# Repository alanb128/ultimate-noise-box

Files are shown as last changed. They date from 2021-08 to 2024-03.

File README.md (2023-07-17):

# ultimate-noise-box
Turn a Raspberry Pi into the ultimate relaxation machine that plays soothing wav files.

## Overview
Here are the features of the Ultimate Noise Machine:
- Produces CD-quality stereophonic audio.
- Uses real audio samples with gapless undetectable looping
- Line level audio output jack to use with high quality powered speakers
- Intuitive control panel with rotary wheel and LCD screen
- Web-based control too with a responsive UI

This is the full-size unit based on a Raspberry Pi 3 with custom 3D-printed faceplate:

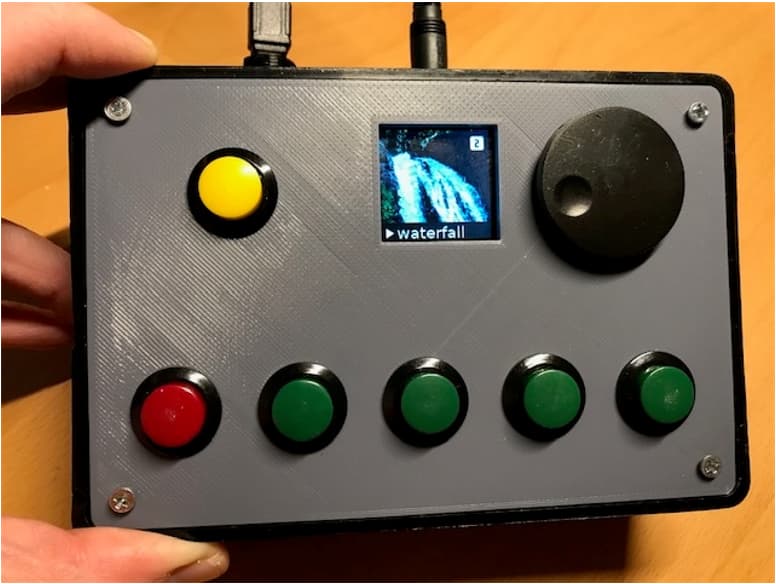
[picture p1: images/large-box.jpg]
Large version


The smaller version uses smaller buttons and a Raspberry Pi Zero 2W:

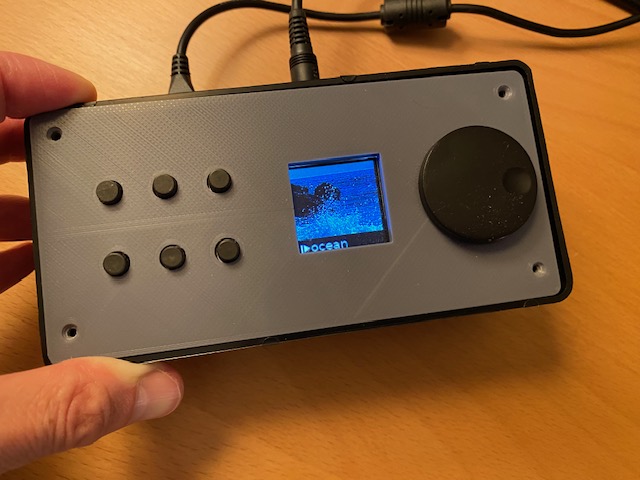
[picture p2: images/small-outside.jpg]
Small version


## Building it

### Parts list

At a minimum, you need a Pi and the audio bonnet specified below. If you don't use the buttons, rotary encoder, or display, you can control the Noise Box from its built-in web page by browsing to the device's IP address or enabling the Public URL feature.

- Raspberry Pi 3, 4, or Zero 2W
- [Adafruit I2S Audio Bonnet](https://www.adafruit.com/product/4037)
- Momentary SPST pushbutton such as [this one](https://www.adafruit.com/product/1504)
- 1.44 inch TFT [LCD screen](https://www.adafruit.com/product/2088)
- [Rotary encoder](https://www.adafruit.com/product/377) (why not get a nice [knob](https://www.adafruit.com/product/2055) too?)
- [I2C Rotary Encoder Breakout](https://www.adafruit.com/product/4991)

### Assembly

Wire the switches into the audio bonnet following the schematic below. You can solder directly into the pads on the bonnet, which show the GPIO number.

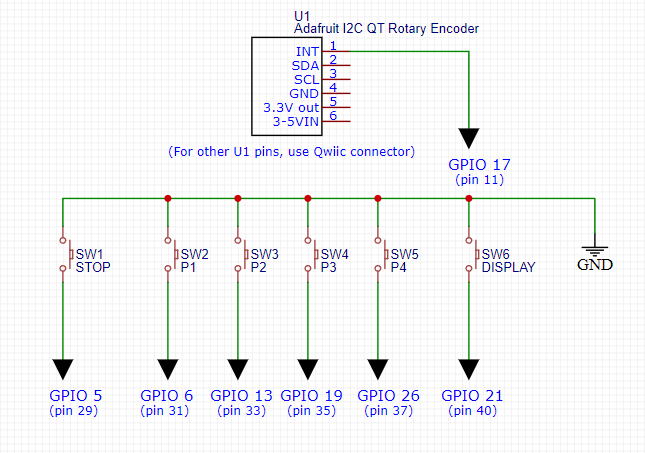
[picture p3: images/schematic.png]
Schematic


Wire the LCD into the bonnet using the diagram for the 1.44" display found [here](https://learn.adafruit.com/adafruit-1-44-color-tft-with-micro-sd-socket/python-wiring-and-setup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).

Solder the rotary encoder to the encoder board as detailed [here](https://learn.adafruit.com/adafruit-i2c-qt-rotary-encoder/overview). Finally, wire the rotary encoder board into the bonnet. You could use the Qwiic connector on one end, but either way the INT terminal on the rotary board will need to be wired in to GPIO 17.

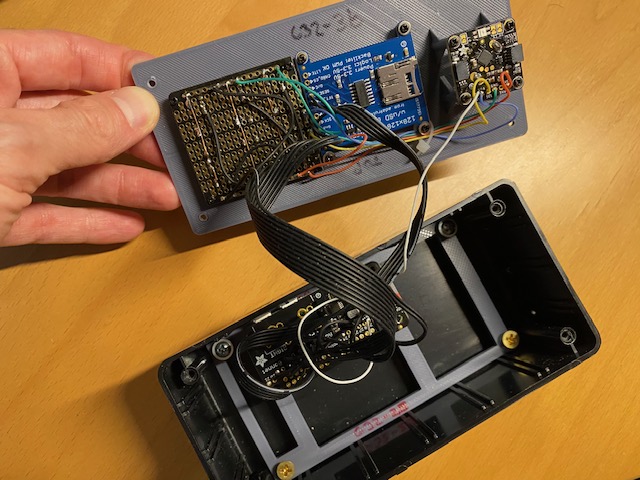
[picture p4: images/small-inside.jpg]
Inside wiring


Attach the audio bonnet to the Pi.

### Case

Use your favorite project case, and to enhance the project, print your own faceplate to mount the controls. You can find STL files in this repo for the 3D faceplates used in the pictures above. Unfortunately [the cases](https://www.radioshack.com/products/radioshack-project-enclosure-6x4x2) used for them no longer appear available from Radio Shack online.

## Software

This project uses the [balena platform](https://www.balena.io/) for ease of deployment, device management and as the best way to run containers on the Pi. Sign up for a free account - the first 10 devices are free and fully featured. After assembling your hardware and creating a balena account, simply click the button below to generate a microSD card image to burn and insert in your Pi:

balena deploy button (https://dashboard.balena-cloud.com/deploy?repoUrl=https://github.com/alanb128/ultimate-noise-box)

After you create a fleet, add a new device. Choose the type of Pi you'll be using and you can also add your WiFi credentials at this point. You'll be able to download the SD card image after you add the device. You can use [balenaEtcher](https://etcher.balena.io/) to burn your SD card image. After powering on your Pi, it should start downloading the software.

After the software has downloaded, you'll need to go into the device configuration in balenaCloud and add the following configuration variable:

`BALENA_HOST_CONFIG_dtoverlay`

With the value:

`"hifiberry-dac","i2s-mmap"`

If you want to make your own changes to the software, clone this repo and use the [balena CLI](https://github.com/balena-io/balena-cli) to push the modified code to your device.

## Setup and use

The unit comes with nine pre-recorded relaxation sounds. To add more sounds, browse to the device's IP address (you can find it on the dashboard) on port 9000. (i.e. 192.168.1.100:9000 - but use your IP) The initial login for the Minio browser is `myminio`/`myminio123` here you can drag and drop additional sound files. They must be of the following type: uncompressed PCM format wav files. The sound file should be optimized for looping playback. If you would like an accompanying image for each sound file, give it the same name but with a .jpg file extension. Images should be 128x128 pixels. After uploading additional files, you should reboot the device from the balenaCloud dashboard.

You can scroll through the available sounds by rotating the wheel. Push the wheel to play the selected sound. The stop button stops playback of the current sound.

The display button cycles through the volume display and the device info display. You can adjust the volume level with the wheel when the volume bar is displayed, however controlling the actual volume is currently not implemented.

The four preset buttons instantly start playing the preset sound. To store a preset, open the web interface to the device by browsing its IP address (port 80).

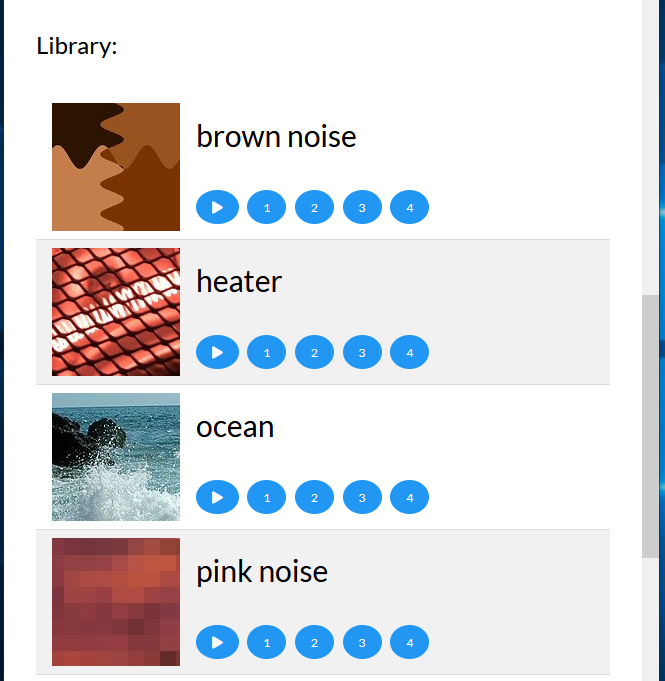
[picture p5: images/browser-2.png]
Web page


Next to each sound you'll see buttons labeled 1 - 4. Click the button number next to a sound to assign it to that preset number.

## How it works

The application is made up of multiple [containers](https://docs.docker.com/get-started/what-is-a-container/) that communicate with each other through APIs and also share a storage volume. This project is a great example of how containers can work together and cleanly separate functionality. Also note how we add entire functionality by pulling images made by the various software authors. 

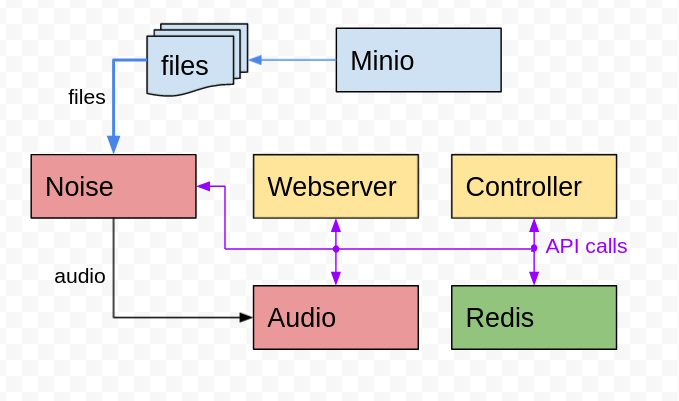
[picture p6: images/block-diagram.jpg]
Block diagram


Here is a summary of the function of each container:

### Noise
This is the Python program that plays back the audio files through the audio block. It uses Pygame to achieve gapless looping playback. The audio files must be in uncompressed PCM wav file format. It exposes an API (using FlaskAPI) 
- `GET /` returns the current status (`status`) and currently playing file (`file`) and a list of valid API calls.
- `POST /play/<noisename>/` immediately starts looping playback of specified noise, and returns the current status (`status`) and currently playing file (`file`)
- `POST /stop/` immediately stops any file playback, and returns the current status (`status`)

Note `<noisename>` and returned file are the name of the noise, with no path or extension, and underscore (_) instead of spaces.

### Webserver
This is a Node/Express webserver that generates a single page for stopping or starting a noise from the library or presets. It is also currently the only place you can assign presets to noises. The four presets mirror the four physical buttons on the hardware control panel. This application uses XMLHttpRequest to communicate with the backend for stopping, starting and assigning presets. It is set to run on port 80 by default and can be made available outside your network if you enable the device's [public URL](https://www.balena.io/docs/learn/develop/runtime/#public-device-urls).

### [Redis](https://redis.io/)
An in-memory data structure store. It can periodically write to the local storage as well. This is used to store and retreive the values of the preset buttons, last volume level and most recently played file.

### [Minio](https://min.io/)
S3 compatible object storage. This provides a web interface for uploading new audio files and their associated jpegs to the device. To access the interface, browse to the local URL using port 9000. To change the username and password, set new values in the `docker-compose.yml` file before first use! (You'll need to clone this repo and push using the CLI in order to do this.)

### Audio
This is the versatile balena [audio block](https://github.com/balenablocks/audio) that runs a PulseAudio server optimized for balenaOS and is the core of [balenaSound](https://sound.balenalabs.io/). We use it here to take care of setting up and routing all audio needs on the Pi hardware, so the noise container just sends its audio here.

### Controller
A custom Python program that responds to button presses on the control panel, reads the rotary dial position and drives the LCD display.

## Credits

Some of the included sounds and their accompanying images were derived from the following royalty-free image and sound libraries:

Waterfall sound by <a href="https://pixabay.com/users/nickype-10327513/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">NickyPe</a> from <a href="https://pixabay.com//?utm_source=link-attribution&utm_medium=referral&utm_campaign=music&utm_content=121190">Pixabay</a>

Splash sound by <a href="https://pixabay.com/users/juliush-3921568/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">JuliusH</a> from <a href="https://pixabay.com/sound-effects//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">Pixabay</a>

Rain sound by <a href="https://pixabay.com/users/sergei_spas-9611130/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">sergei_spas</a> from <a href="https://pixabay.com/sound-effects//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">Pixabay</a>

Brown image extracted from photo by <a href="https://unsplash.com/@pawel_czerwinski?utm_source=unsplash&utm_medium=referral&utm_content=creditCopyText">Pawel Czerwinski</a> on <a href="https://unsplash.com/backgrounds/colors/brown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">Unsplash</a>

Pink noise image extracted from photo by <a href="https://unsplash.com/@joelfilip?utm_source=unsplash&utm_medium=referral&utm_content=creditCopyText">Joel Filipe</a> on <a href="https://unsplash.com/photos/Mbf3xFiC1Zo?utm_source=unsplash&utm_medium=referral&utm_content=creditCopyText">Unsplash</a>

Underwater image extracted from photo by <a href="https://unsplash.com/@hisarahlee?utm_source=unsplash&utm_medium=referral&utm_content=creditCopyText">Sarah Lee</a> on <a href="https://unsplash.com/photos/QURU8IY-RaI?utm_source=unsplash&utm_medium=referral&utm_content=creditCopyText">Unsplash</a>

Rain image extracted from photo by <a href="https://unsplash.com/@janfillem?utm_source=unsplash&utm_medium=referral&utm_content=creditCopyText">Jan-Willem</a> on <a href="https://unsplash.com/photos/FobwhDUgdrk?utm_source=unsplash&utm_medium=referral&utm_content=creditCopyText">Unsplash</a>
  
Splash image extracted from photo by <a href="https://unsplash.com/@amadejtauses?utm_source=unsplash&utm_medium=referral&utm_content=creditCopyText">Amadej Tauses</a> on <a href="https://unsplash.com/photos/xWOTojs1eg4?utm_source=unsplash&utm_medium=referral&utm_content=creditCopyText">Unsplash</a>

Waterfall photo by <a href="https://unsplash.com/@nathananderson?utm_source=unsplash&utm_medium=referral&utm_content=creditCopyText">Nathan Anderson</a> on <a href="https://unsplash.com/wallpapers/nature/waterfall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">Unsplash</a>

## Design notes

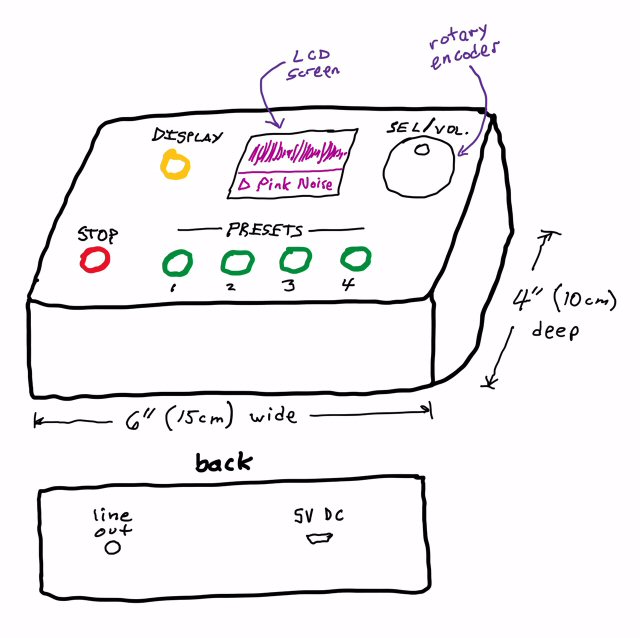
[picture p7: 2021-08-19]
initial_plan-50.jpeg

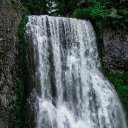
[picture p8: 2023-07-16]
noise/assets/waterfall.jpg

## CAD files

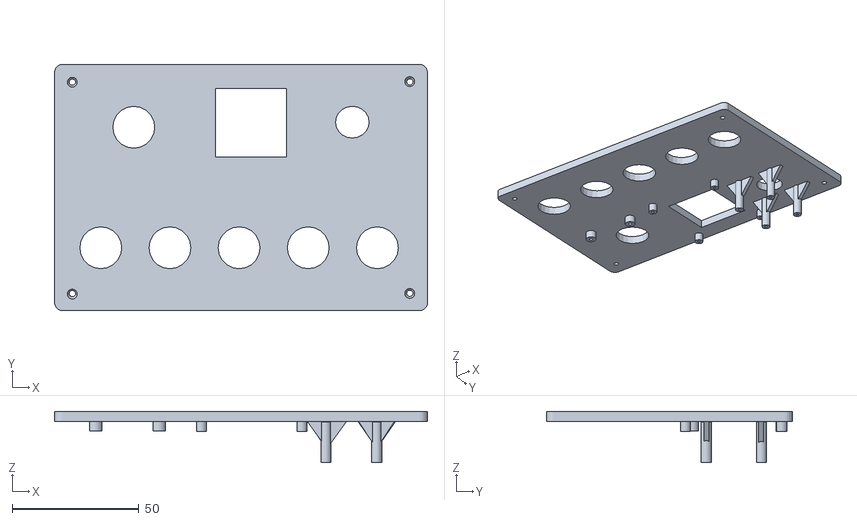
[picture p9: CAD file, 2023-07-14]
stl/large-faceplate.stl
147.0 x 97.0 x 20.2

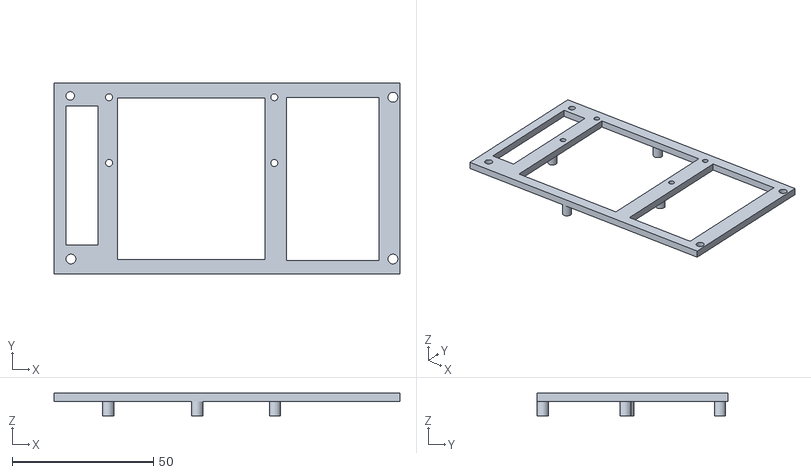
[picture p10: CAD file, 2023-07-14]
stl/small-case-bracket.stl
122.5 x 67.5 x 8.00

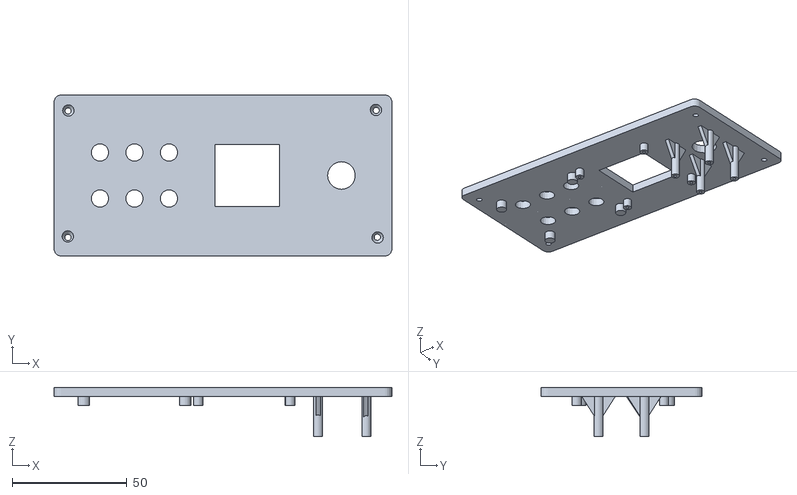
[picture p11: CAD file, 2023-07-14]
stl/small-faceplate.stl
147.0 x 70.0 x 21.5

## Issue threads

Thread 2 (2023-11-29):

Error trying to deploy release at the minio phase

matrix9777, 2023-11-29:
Would you have a solution to this error?

[Error]       Some services failed to build:
[Error]         Service: minio
[Error]           Error: no matching manifest for linux/arm/v6 in the manifest list entries
[Info]        Built on 3c65b7a
[Error]       Not deploying release.

alanb128, 2023-11-29:
I don't think Minio has a version for the armV6 architecture. Are you using a Pi Zero? Upgrading to an armV7 or higher device like the Pi 3, 4 or Zero 2 would probably fix it. To make it work on your current device, you could delete the Minio section of the docker-compose but you would need to use another method to upload the audio/image files to your device.

matrix9777, 2023-11-29:
Thank you for the fast response. Do you have a suggestion on the best way to modify the code that it's trying to push to Balena? It doesn't give me an edit option on the Balena site, it just tries to deploy, then errors out when it can't complete the operation without an option to edit what it's trying to compile.
Thanks in advance.

alanb128, 2023-11-30:
You can clone this repo to your local machine, make the modifications, then push the changed code as a release to your fleet (of one device) using the balena CLI. (It may sound like a lot of steps, but it's actually pretty quick.) You can see the step-by-step instructions here: https://docs.balena.io/learn/getting-started/raspberrypi3/python/ - you've already completed some of the steps, so note the section about using the CLI.

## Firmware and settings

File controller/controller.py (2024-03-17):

import digitalio 
import board 
from PIL import Image, ImageDraw, ImageFont 
try:
    import adafruit_rgb_display.ili9341 as ili9341 
    import adafruit_rgb_display.st7789 as st7789 # pylint: disable=unused-import 
    import adafruit_rgb_display.hx8357 as hx8357 # pylint: disable=unused-import 
    import adafruit_rgb_display.st7735 as st7735 # pylint: disable=unused-import 
    import adafruit_rgb_display.ssd1351 as ssd1351 # pylint: disable=unused-import 
    import adafruit_rgb_display.ssd1331 as ssd1331 # pylint: disable=unused-import
except:
    print("No display found, going headless!")
    USE_DISPLAY = False
else:
    USE_DISPLAY = True

import time 
import subprocess 
import datetime 
import RPi.GPIO as GPIO 
import requests
import redis 
import os
try:
    from adafruit_seesaw import seesaw, rotaryio
except:
    print("No rotary encoder found, disabling rotary control!")
    USE_ROTARY = False
else:
    USE_ROTARY = True

# Adafruit I2C QT Rotary Encoder
# Using the INT output on Pi GPIO 17
try:
    seesaw = seesaw.Seesaw(board.I2C(), addr=0x36)
except:
    print("Error initializing the rotary encoder board.")
    USE_ROTARY = False
else:
    seesaw_product = (seesaw.get_version() >> 16) & 0xFFFF
    print("Found seesaw supported product {}".format(seesaw_product))
    if seesaw_product != 4991:
        print("Wrong firmware loaded for QT encoder?  Expected 4991")
    # Set up the rotary click button, and add to interrupt
    seesaw.pin_mode(24, seesaw.INPUT_PULLUP)  # Pin on the QT
    seesaw.set_GPIO_interrupts(1 << 24, True)
    seesaw.enable_encoder_interrupt()

# TFT configuration for CS and DC pins:
cs_pin = digitalio.DigitalInOut(board.CE0) #pin24
dc_pin = digitalio.DigitalInOut(board.D25) #pin22
reset_pin = digitalio.DigitalInOut(board.D24) #pin18

# Config for display baudrate (default max is 24mhz):
BAUDRATE = 24000000

# Setup SPI bus using hardware SPI:
spi = board.SPI()

try:
    # pylint: disable=line-too-long
    # Create the display:
    # disp = st7789.ST7789(spi, rotation=90,                            # 2.0" ST7789
    # disp = st7789.ST7789(spi, height=240, y_offset=80, rotation=180,  # 1.3", 1.54" ST7789
    # disp = st7789.ST7789(spi, rotation=90, width=135, height=240, x_offset=53, y_offset=40, # 1.14" ST7789
    # disp = hx8357.HX8357(spi, rotation=180,                           # 3.5" HX8357
    disp = st7735.ST7735R(spi, rotation=90,                           # 1.8" ST7735R
    #disp = st7735.ST7735R(spi, rotation=270, height=128, x_offset=2, y_offset=3,   # 1.44" ST7735R
    # disp = st7735.ST7735R(spi, rotation=90, bgr=True,                 # 0.96" MiniTFT ST7735R
    # disp = ssd1351.SSD1351(spi, rotation=180,                         # 1.5" SSD1351
    # disp = ssd1351.SSD1351(spi, height=96, y_offset=32, rotation=180, # 1.27" SSD1351
    # disp = ssd1331.SSD1331(spi, rotation=180,                         # 0.96" SSD1331
        cs=cs_pin,
        dc=dc_pin,
        rst=reset_pin,
        baudrate=BAUDRATE,
    )
except:
    print("No display or error setting up display.")
    disp = False
    USE_DISPLAY = False

if USE_DISPLAY:
    # Create blank image for drawing.
    # Make sure to create image with mode 'RGB' for full color.
    if disp.rotation % 180 == 90:
        height = disp.width  # we swap height/width to rotate it to landscape!
        width = disp.height
    else:
        width = disp.width  # we swap height/width to rotate it to landscape!
        height = disp.height
else:
    # set a default h, w even if no display so image routines don't error out
    width = 128
    height = 128

# Main RGB image
image = Image.new("RGB", (width, height))

# image for info area
img_info = Image.new("RGB", (128, 20), (0, 0, 0))

# create idle image
idle_image = Image.new("RGB", (width, height))

# image for about screen
img_about = Image.new("RGB", (width, height))

# tiny images for fwd/rev wheel icon
img_right = Image.new('RGB', (20, 20), (0, 0, 0))
img_left = Image.new('RGB', (20, 20), (0, 0, 0))

# Drawing object for main display image
draw = ImageDraw.Draw(image)

wav_list = []  # list of available wav files to play (strings)
img_list = []  # list of images to display for each wav file (images)
vol_list = []  # list of volume bars representing volumes (images)
noise_pointer = 0  # index of currently displayed noise image when rotating wheel (int)
rotary_pos = 0  # keeps track of wheel position
now_playing = ""  # name of currently playing file or emply string
display_mode = 0  # int display mode (0-2)
current_volume = 10  # default current volume if none saved (0-20)
new_volume = 10 # variable to see if volume has changed
loop_count = 0  # loop counter for checking the current sound status
IMAGE_PATH = os.getenv('MEDIA_PATH', "/data/my_data/noise/")  # string path to noise and images
ASSET_PATH = os.getenv('ASSET_PATH', "/data/my_data/assets/") # string path to non-noise assets
TEXT_FONT = ImageFont.truetype("/usr/share/fonts/truetype/dejavu/DejaVuSans.ttf", 18)
ICON_FONT = ImageFont.truetype("/usr/src/app/materialdesignicons-webfont.ttf", 20)
DEBOUNCE = 600  # switch debounce time in ms
rot_first = datetime.datetime.now()
rot_last = datetime.datetime.now()

P1_GPIO = 6
P2_GPIO = 13
P3_GPIO = 12 # was 19
P4_GPIO = 20
DISP_GPIO = 22 # was 21
STOP_GPIO = 5

def lib_setup():
    #
    # Generate list of all sound files available,
    # create list of all images with titles burned in,
    # create volume image list
    # create wheel icon images
    #
    global wav_list, img_list, img_info, img_left, img_right
    # Get all sound files in folder
    dir_list = os.listdir(IMAGE_PATH)
    font = ImageFont.truetype("/usr/share/fonts/truetype/dejavu/DejaVuSans.ttf", 18)
    # for each file:
    for d in dir_list:
        if d[-4:] == ".wav":
            save_image = Image.new("RGB", (width, height))
            save_draw = ImageDraw.Draw(save_image)
            save_draw.rectangle((0, 0, width, height), fill=(0, 0, 0)) # draw black box
            noise_name = d[:len(d) - 4]
            wav_list.append(noise_name)
            try:
                i = Image.open(IMAGE_PATH + noise_name + ".jpg")
            except:
                i = Image.open(ASSET_PATH + "default.jpg")
            if width > 128:
                i = i.resize((width, 128))
            save_image.paste(i, (0,0))
            save_image.paste(img_info, (0, 108))
            text = noise_name.replace("_", " ")
            save_draw.text((20, 110), text, font=font, fill=(255, 255, 255),)
            img_list.append(save_image)
    # generate a list of 20 vol images:
    for v in range(0, 21):
        save_image = Image.new("RGB", (width, height))
        save_draw = ImageDraw.Draw(save_image)
        save_draw.rectangle((0, 0, width, height), fill=(0, 0, 0))  # draw black box
        i = Image.open(ASSET_PATH + "vol_" + "{:0>3}".format(v * 5) + ".jpg")
        save_image.paste(i, (0,50))
        text = "volume: " + str(v * 5) + " %"
        save_draw.text((20, 110), text, font=font, fill=(255, 255, 255),)
        save_draw.text((1, 110), "\U000F057F", font=ICON_FONT, fill=(255, 255, 255),)
        vol_list.append(save_image)

    # wheel icon images
    wheel_draw = ImageDraw.Draw(img_left)
    wheel_draw.text((1, 1), "\U000F04D5", font=ICON_FONT, fill=(255, 255, 255),)  # draw the left sel icon
    wheel_draw = ImageDraw.Draw(img_right)
    wheel_draw.text((1, 1), "\U000F04D7", font=ICON_FONT, fill=(255, 255, 255),)  # draw the right sel icon

def create_idle_image():
    #
    # Create the idle image!
    #
    global idle_image
    idle_image_raw = Image.new("RGB", (width, height))
    try:
        idle_image_raw = Image.open(ASSET_PATH + "idle.jpg")
    except:
        # if no idle image found, draw a rectangle instead
        idle_image_draw = ImageDraw.Draw(idle_image_raw)
        idle_image_draw.rectangle((0, 0, width, height), fill=(0, 100, 200))
    if width > 128:
        idle_image_raw = idle_image_raw.resize((width, 128))
    idle_image.paste(idle_image_raw, (0,0))  # use idle image
    idle_draw = ImageDraw.Draw(idle_image)
    idle_image.paste(img_info, (0, 108))
    idle_draw.text((1, 110), "\U000F04DB", font=ICON_FONT, fill=(255, 255, 255),)  # draw the stop icon
    #font = ImageFont.truetype("/usr/share/fonts/truetype/dejavu/DejaVuSans.ttf", 18)
    idle_draw.text((20, 110), "(idle)", font=TEXT_FONT, fill=(255, 255, 255),)

# Setup initial state
def init_controller():
    print("init display")
    global disp, image, draw, now_playing, idle_image

    try:
        image = Image.open(ASSET_PATH + "splash.jpg")
    except:
        print("Error accessing splash.jpg - using default splash screen instead.")
        # Draw a blue box for init display
        draw.rectangle((0, 0, width, height), fill=(0, 0, 72))

        # Load a TTF Font
        font = ImageFont.truetype("/usr/share/fonts/truetype/dejavu/DejaVuSans.ttf", 24)

        # Draw splash screen
        text = "Welcome!"
        draw.text((3, 10), text, font=font, fill=(255, 255, 0),)
    else:
        if USE_DISPLAY:
            if width > 128:
                image = image.resize((width, 128))
            disp.image(image)
    time.sleep(1)
    lib_setup()
    time.sleep(1)
    create_idle_image()
    time.sleep(1)
    display_info()

    # get current status
    r = requests.get('http://noise:5000/')
    j = r.json()

    print(j)
    if j["status"] == "stop":
        now_playing = ""
        display_now(idle_image)
    else:
        now_playing = j["file"]
        print("now playing: ", now_playing)
        display_now(img_list[wav_list.index(now_playing)])

def current_status():
    #
    # Calls the noise service and updates display
    #
    # get current status
    r = requests.get('http://noise:5000/')
    j = r.json()
    if j["status"] == "stop":
        if now_playing != "":
          now_playing = ""
          display_now(idle_image)
    else:
        now_playing = j["file"]
        print("now playing: ", now_playing)
        display_now(img_list[wav_list.index(now_playing)])

def display_info():
    #
    # Display device info on LCD
    #
    global img_about
    draw_about = ImageDraw.Draw(img_about)
    font1 = ImageFont.truetype("/usr/share/fonts/truetype/dejavu/DejaVuSans.ttf", 16)
    font2 = ImageFont.truetype("/usr/share/fonts/truetype/dejavu/DejaVuSans.ttf", 14)
    img_about.paste(img_info, (0, 108))
    draw_about.text((22, 110), "device info", font=TEXT_FONT, fill=(255, 255, 255),)
    draw_about.text((1, 110), "\U000F02FD", font=ICON_FONT, fill=(255, 255, 255),)
    # Prep screen to cover "Reading..."
    draw_about.rectangle((0, 0, width, 107), fill=(0, 0, 72))  # draw blue bkgd
    # Use supervisor API to get info
    try:
        r = requests.get(os.getenv('BALENA_SUPERVISOR_ADDRESS') + "/v1/device?apikey=" + os.getenv('BALENA_SUPERVISOR_API_KEY'))
    except:
        draw_about.text((1, 7), "(info unavailable)", font=font2, fill=(255, 165, 0),)
    else:
        j = r.json()
        draw_about.text((1, 7), "IP:", font=font2, fill=(255, 165, 0),)
        draw_about.text((1, 41), "balenaOS:", font=font2, fill=(255, 165, 0),)
        draw_about.text((1, 75), "REL:", font=font2, fill=(255, 165, 0),)
        draw_about.text((1, 23), j["ip_address"], font=font2, fill=(255, 255, 255),)
        draw_about.text((1, 57), j["os_version"][9:], font=font2, fill=(255, 255, 255),)
        draw_about.text((1, 91), j["commit"][:7], font=font2, fill=(255, 255, 255),)
        
def button_stop(channel):
    #
    # stop payback
    #
    global now_playing
    r = requests.post('http://noise:5000/stop/')
    print("Stop button pressed.")
    now_playing = ""
    display_now(idle_image)

def button_display(channel):
    #
    # change display mode
    #
    global display_mode, display_timer
    print("pressed display button")
    display_mode = display_mode + 1
    if display_mode == 3:
        display_mode = 0
    # Decide what to display
    if display_mode == 0:
        if now_playing == "":
            display_now(idle_image)
        else:
            display_now(img_list[wav_list.index(now_playing)])
    elif display_mode == 1:
        image.paste(vol_list[current_volume], (0,0))
        if USE_DISPLAY:
            disp.image(image)
    elif display_mode == 2:
        if USE_DISPLAY:
            disp.image(img_about)

def button_preset(channel):
    #
    # play a preset
    #
    # get preset number (1-4) from channel
    preset_channel = [P1_GPIO, P2_GPIO, P3_GPIO, P4_GPIO]
    presety = preset_channel.index(channel)
    # get preset name value from redis
    r = redis.StrictRedis(host='redis', port=6379, db=0, decode_responses=True)
    p = r.get("p" + str(presety + 1))
    print("Preset {0} ({1}) pressed.".format(p, presety))
    # play/display the file image
    if p is None:
        print("No preset value for {}".format(presety))
    else:
        text_icon = ["\U000F03A4", "\U000F03A7", "\U000F03AA", "\U000F03AD"]
        play_file(p, text_icon[presety])

def button_rotary_click():
    #
    # called on rotary click
    #

    global display_mode

    if display_mode == 0:
        if wav_list[noise_pointer] != now_playing:
            play_file(wav_list[noise_pointer])
    else:  # change display mode
        button_display(0)

def play_file(noise_name, extra_icon=""):
    #
    # Play the specified file, update the display
    #
    global now_playing, noise_pointer, display_mode
    if noise_name == '':
        print("Warning! Noise with no name requested.")
        return
    display_mode = 0
    now_playing = noise_name
    noise_pointer = wav_list.index(now_playing)
    r = requests.post('http://noise:5000/play/' + now_playing + "/")
    display_now(img_list[wav_list.index(now_playing)], extra_icon)

def display_now(d_img, extra_icon=""):
    #
    # sends specified image to lcd display
    # if "" then display idle image
    #
    
    d_img_draw = ImageDraw.Draw(d_img)
    #image.paste(d_img, (0,0))  # use now playing image
    #print("Now playing: {0}, wav_list.index(now_playing): {1}".format(now_playing, wav_list.index(now_playing)))
    d_img_draw.text((1, 110), "\U000F040A", font=ICON_FONT, fill=(255, 255, 255),)  # draw the play icon
    if len(extra_icon) > 0:   # draw the extra icon
        d_img_draw.text((105, 5), extra_icon, font=ICON_FONT, fill=(255, 255, 255),)

    if USE_DISPLAY:
        disp.image(d_img)

def rotary_incoming(r):
    #
    # Triggered by rotary QT interrupt
    # when rotary wheel is turned or clicked
    #
    global rotary_pos, rot_first, rot_last
    current_pos = seesaw.encoder_position()
    rot_btn = not(seesaw.digital_read(24))
    print("rotary pos: {0}; current_pos: {1}; rot_btn: {2}".format(rotary_pos, current_pos, rot_btn))
    if rotary_pos == current_pos:
        if rot_btn == True:
            print("Button pressed!")
            button_rotary_click()
    else:
        #rot_first = datetime.datetime.now()
        #diff = rot_first - rot_last
        if current_pos < rotary_pos:
            print("Turned right {}".format(current_pos))
            # Action on every other (even) click
            if (current_pos % 2) == 0:
                wheel_right()
        else:
            print("Turned left {}".format(current_pos))
            # Action on every other (even) click
            if (current_pos % 2) == 0:
                wheel_left()
        #rot_last = datetime.datetime.now()
        #print("diff: {}".format(diff.microseconds))
    rotary_pos = current_pos
    #print("seesaw rotary data updated! {0}, {1}".format(rot_pos, rot_btn))
    
def wheel_right():
    #
    # Wheel turned right (>)
    #
    
    global disp, noise_pointer, current_volume, image

    if display_mode == 0:
        noise_pointer = noise_pointer + 1
        if noise_pointer > len(img_list) - 1:
            noise_pointer = 0
        image.paste(img_list[noise_pointer], (0,0))
        image.paste(img_right, (1, 110))
        #draw.text((50, 50), "RIGHT", font=TEXT_FONT, fill=(255, 255, 255),)
        #draw.text((1, 110), "\U000F04D7", font=ICON_FONT, fill=(255, 255, 255),)  # draw the right sel icon
    elif display_mode == 1:
        current_volume = current_volume + 1
        if current_volume > 19:
            current_volume = 19
        else:
            image.paste(vol_list[current_volume], (0,0))
    
    if USE_DISPLAY:
        disp.image(image)

def wheel_left():
    #
    # Wheel turned left (<)
    #
 
    global noise_pointer, current_volume, draw

    if display_mode == 0:
        noise_pointer = noise_pointer - 1
        if noise_pointer < 0:
            noise_pointer = len(img_list) - 1
        image.paste(img_list[noise_pointer], (0,0))
        image.paste(img_left, (1, 110))
        draw.text((1, 110), "\U000F04D5", font=ICON_FONT, fill=(255, 255, 255),)  # draw the left sel icon
    elif display_mode == 1:
        current_volume = current_volume - 1
        if current_volume < 0:
            current_volume = 0
        else:
            image.paste(vol_list[current_volume], (0,0))
    if USE_DISPLAY:
        disp.image(image)

#
#     %%%%%%%%%%%%  Initial program flow continues here %%%%%%
#

print("Starting...")

# Set button inputs
# stop
GPIO.setup(STOP_GPIO, GPIO.IN, pull_up_down=GPIO.PUD_UP)
GPIO.add_event_detect(STOP_GPIO, GPIO.RISING, callback=button_stop, bouncetime=DEBOUNCE)

#display
GPIO.setup(DISP_GPIO, GPIO.IN, pull_up_down=GPIO.PUD_UP)
GPIO.add_event_detect(DISP_GPIO, GPIO.RISING, callback=button_display, bouncetime=DEBOUNCE+200)

# preset 1
GPIO.setup(P1_GPIO, GPIO.IN, pull_up_down=GPIO.PUD_UP)
GPIO.add_event_detect(P1_GPIO, GPIO.RISING, callback=button_preset, bouncetime=DEBOUNCE)

# preset 2
GPIO.setup(P2_GPIO, GPIO.IN, pull_up_down=GPIO.PUD_UP)
GPIO.add_event_detect(P2_GPIO, GPIO.RISING, callback=button_preset, bouncetime=DEBOUNCE)

# preset 3
GPIO.setup(P3_GPIO, GPIO.IN, pull_up_down=GPIO.PUD_UP)
GPIO.add_event_detect(P3_GPIO, GPIO.RISING, callback=button_preset, bouncetime=DEBOUNCE)

#preset 4
GPIO.setup(P4_GPIO, GPIO.IN, pull_up_down=GPIO.PUD_UP)
GPIO.add_event_detect(P4_GPIO, GPIO.RISING, callback=button_preset, bouncetime=DEBOUNCE)

#rotaryio interrupt
GPIO.setup(17, GPIO.IN, pull_up_down=GPIO.PUD_UP)
GPIO.add_event_detect(17, GPIO.FALLING, callback=rotary_incoming)

# set initial display states
init_controller()

# get saved volume, if available
redis_conn = redis.StrictRedis(host='redis', port=6379, db=0, decode_responses=True)
v = redis_conn.get("v")
if v is not(None):
    current_volume = int(v)
new_volume = current_volume

while True:
    loop_count = loop_count + 1
    if loop_count == 5:
        loop_count = 0
        #  Check to see if some other process has changed the status
        try:
            r = requests.get('http://noise:5000/')
        except:
            print("Error accessing noise service.")
        j = r.json()
        if j["status"] == "stop":
            if now_playing != "":
                now_playing = ""
                display_now(idle_image)
        else:
            if now_playing != j["file"]:
                now_playing = j["file"]
                display_now(img_list[wav_list.index(now_playing)])
        # See if we need to save a new volume level in Redis
        if current_volume != new_volume:
            # Save volume in Redis
            try:
                redis_conn.set('v', current_volume)
            except:
                print("Error saving volume data to Redis.")
            new_volume = current_volume

    time.sleep(2)

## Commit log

2022-01-20 Pin base image date
2023-07-14 Added STL files
    [large-faceplate.stl, small-case-bracket.stl, small-faceplate.stl]
2023-07-16 Features, bug fixes, docs
    [controller.py]
